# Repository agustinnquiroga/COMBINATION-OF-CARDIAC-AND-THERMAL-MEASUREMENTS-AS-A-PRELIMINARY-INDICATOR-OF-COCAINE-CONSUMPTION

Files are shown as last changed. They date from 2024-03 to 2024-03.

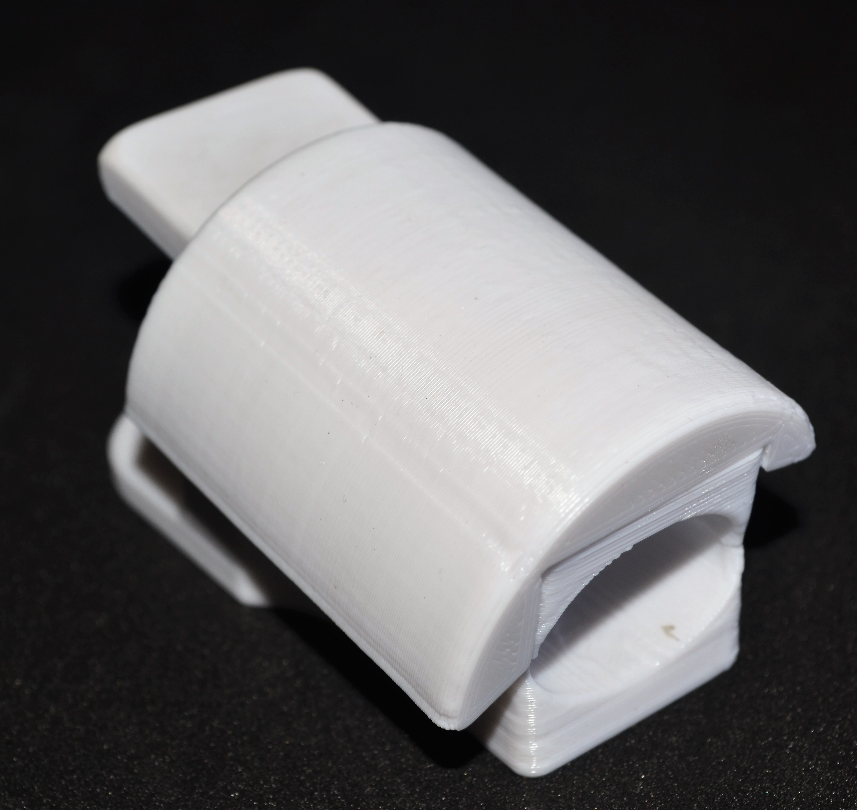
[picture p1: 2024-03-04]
DESIGN/IMAGENES/DSC_0425.JPG

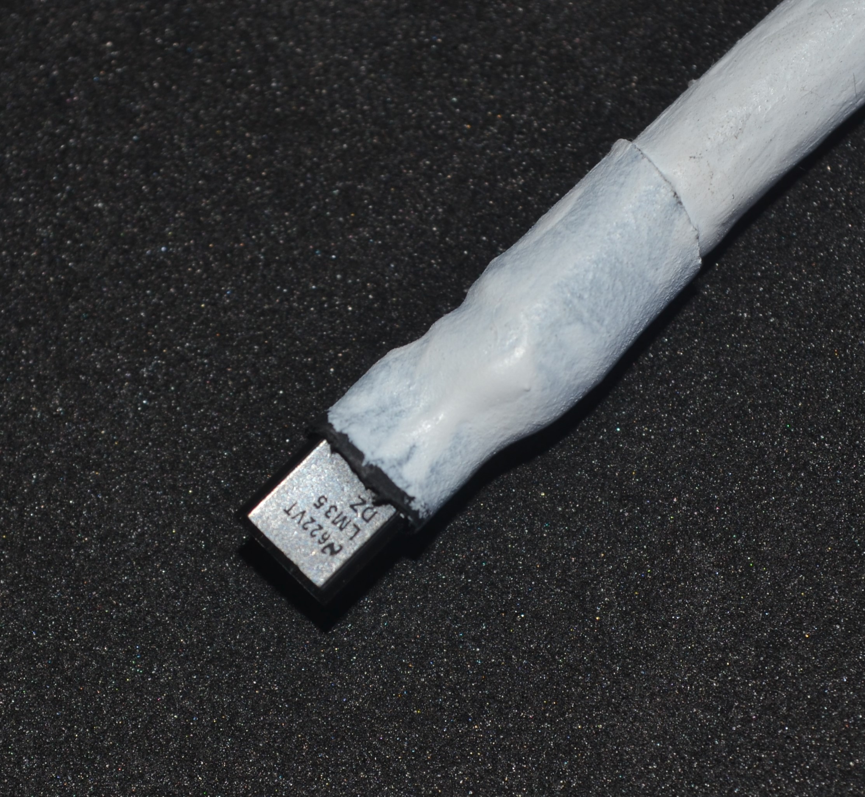
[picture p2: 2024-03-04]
DESIGN/IMAGENES/DSC_0422.JPG

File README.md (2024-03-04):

# COMBINATION-OF-CARDIAC-AND-THERMAL-MEASUREMENTS-AS-A-PRELIMINARY-INDICATOR-OF-COCAINE-CONSUMPTION

En Argentina según un estudio de la
Secretaría de Políticas Integrales sobre Drogas
de la Nación Argentina (Sedronar), el 5,3%
de la población entre 12 y 65 años consumió
cocaína alguna vez en su vida, 1,5% declaró
consumo de cocaína en el último año y 0.7% son
consumidores habituales lo que representa que
dos millones de personas admitieron consumir
alguna vez en su vida, seiscientas mil en el
último año y trescientas mil son consumidoras
recurrentes. Ya que la misma produce una
estimulación del sistema nervioso simpático
es de suma importancia detectar cuando una
persona se encuentra bajos los efectos de la
droga con el fin de que no realice actividades
que demanden el funcionamiento óptimo de
todos sus sistemas.
Entre los parámetros que altera el consumo de
cocaína se encuentran la temperatura corporal
y la frecuencia cardíaca, aumentando los valores
normales registrados para una persona que se
halla en reposo y saludable. Basándonos en los
parámetros mencionados, el presente trabajo
busca diseñar un dispositivo capaz de medir
el pulso y temperatura corporal del sujeto de
estudio, con el fin de constatar si el individuo
posee signos vitales con características similares
a los de una persona que se encuentra bajo los
efectos de la droga.
La frecuencia cardíaca se registrará a través
de un sensor infrarrojo, compuesto por un diodo
emisor de luz infrarroja y un fototransistor
receptor de estas ondas electromagnéticas. El
sensor de coloca en el dedo pulgar y es capaz de
medir los cambios de volumen de sangre en las
arterias debido a la mayor reflexión de luz. La
temperatura corporal se evaluará mediante un
sensor de temperatura analógico, colocado en la
axila del sujeto. A partir de la comparación de
los valores obtenidos se entregará un resultado.

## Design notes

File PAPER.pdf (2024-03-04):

# Test de cocaína a partir de ritmo cardíaco y temperatura corporal

### A. N. Quiroga Baigorri,∗ M. S. Moyano, G. Quintero, and P. Y. Teruya

Instituto de Bioingeniería, Facultad de Ingeniería, Universidad de Mendoza, Boulogne Sur Mer 683, Mendoza

E-mail: a.quiroga@um.edu.ar

## Resumen

En Argentina según un estudio de la Secretaría de Políticas Integrales sobre Drogas de la Nación Argentina (Sedronar), el 5,3% de la población entre 12 y 65 años consumió cocaína alguna vez en su vida, 1,5% declaró consumo de cocaína en el último año y 0.7% son consumidores habituales lo que representa que dos millones de personas admitieron consumir alguna vez en su vida, seiscientas mil en el último año y trescientas mil son consumidoras recurrentes. Ya que la misma produce una estimulación del sistema nervioso simpático es de suma importancia detectar cuando una persona se encuentra bajos los efectos de la droga con el fin de que no realice actividades que demanden el funcionamiento óptimo de todos sus sistemas.
Entre los parámetros que altera el consumo de cocaína se encuentran la temperatura corporal y la frecuencia cardíaca, aumentando los valores normales registrados para una persona que se halla en reposo y saludable. Basándonos en los parámetros mencionados, el presente trabajo busca diseñar un dispositivo capaz de medir el pulso y temperatura corporal del sujeto de estudio, con el fin de constatar si el individuo posee signos vitales con características similares a los de una persona que se encuentra bajo los efectos de la droga.
La frecuencia cardíaca se registrará a través de un sensor infrarrojo, compuesto por un diodo emisor de luz infrarroja y un fototransistor receptor de estas ondas electromagnéticas. El sensor de coloca en el dedo pulgar y es capaz de medir los cambios de volumen de sangre en las arterias debido a la mayor reflexión de luz. La temperatura corporal se evaluará mediante un sensor de temperatura analógico, colocado en la axila del sujeto. A partir de la comparación de los valores obtenidos se entregará un resultado.

## Introducción

La cocaína copia los efectos del sistema nervioso simpático, se inician todas las respuestas orgánicas asociadas a la reacción de lucha o huida: aumentan la tensión arterial y el ritmo cardíaco, contraen los vasos sanguíneos, dilatan los bronquíolos de los pulmones, aumentan el azúcar en la sangre, aumenta la temperatura corporal y, en general, preparan al cuerpo para una emergencia. ¹
En este trabajo solo se hará enfoque a las modificaciones neurológicas que tienen relación con la frecuencia cardíaca y la temperatura corporal.
La frecuencia cardíaca se registrará a través de un sensor infrarrojo, compuesto por un diodo emisor de luz infrarroja y un fototransistor receptor de estas ondas electromagnéticas. El sensor de coloca en el dedo pulgar y es capaz de medir los cambios de volumen de sangre en las arterias debido a la mayor reflexión de luz. La temperatura corporal se evaluará mediante un sensor de temperatura analógico, colocado en la axila del sujeto. A partir de la comparación de los valores obtenidos se entregará un resultado.

## Herramientas y Métodos

### Hardware

La metodología para la adquisición tanto de la señal de temperatura proveniente del sensor LM35 y de la señal de pulso procedente de el sensor de pulso consiste de las etapas detalladas en la Figura 1.

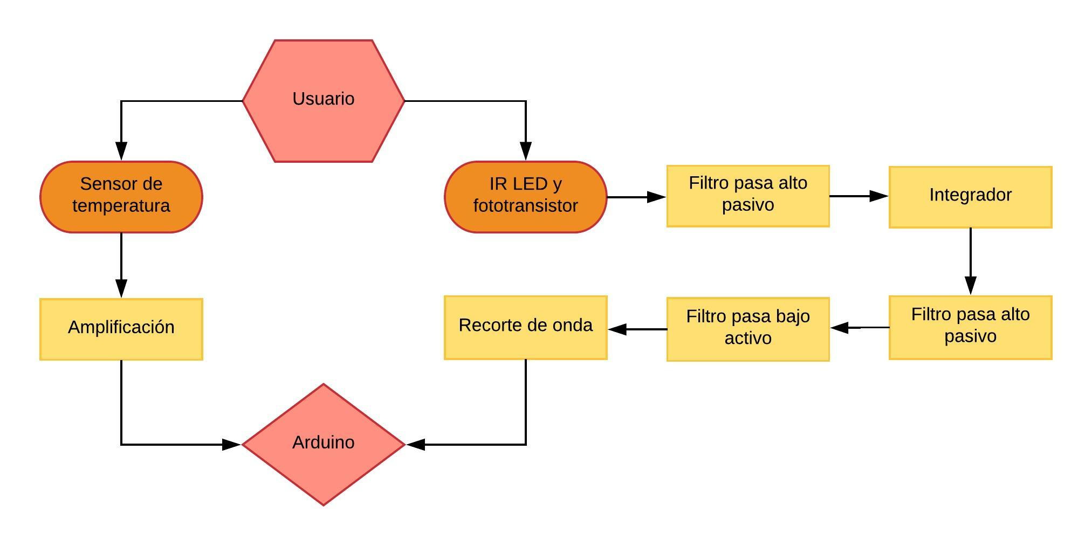
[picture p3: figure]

Figura 1: Diagrama de bloques que especifica las etapas necesarias para la obtención de las señales.

Sensor de temperatura

Se utilizó un circuito integrado LM35 con una tensión de salida lineal proporcional a la temperatura centígrada. El sensor entrega en la salida un voltaje equivalente de:

V out = 0mV + 10.0mV/◦C | (1)

Amplificación

Se acopló a la salida del integrado un amplificador de señal con ganancia de 8 para aprovechar la resolución del convertidor analógico/digital de Arduino. ²,3
En la Tabla 1 se denota el rango de temperatura que logra sensar el dispositivo, junto con las tensiones que se obtendrán a la salida del sensor y luego de que la señal sea amplificada.

Tabla 1: Voltajes

Temperatura Vout LM35 Vout Amp. 4

◦C | 40mV | 0.32V
35◦C | 350mV | 2.8V
40◦C | 400mV | 3.2V
62.5◦C | 625mV | 5V

Sensor de pulso

El pulsómetro se basa en un sensor infrarrojo, compuesto por un diodo emisor de luz infrarroja (IR LED) y un fototransistor receptor de estas ondas electromagnéticas. Las etapas de acondicionamiento de la señal son:

IR LED y fototransistor

Se utilizó un IR LED L53 el cual tiene una corriente máxima de alimentación de 50mA. En tanto el fototransistor se colocó en una configuración emisor común con una corriente mínima de alimentación de 0.1mA.

Filtro pasa alto pasivo

Se acopló un filtro pasa alto pasivo con la finalidad de amortiguar el ruido que posee frecuencias hasta 2.34Hz. Esta etapa tiene también la función de desacoplar la componente continua de la corriente gracias a la utilización de un capacitor en serie con la salida del fototransistor.
Un filtro con las mismas características se adjunta a la salida del amplificador operacional integrador no inversor.

Amplificador operacional integrador no inversor

Se acopla a la salida del filtro pasa alto pasivo un amplificador operacional integrador no inversor, debido a este tratamiento se consigue una señal más nítida y estable. Teniendo en cuenta la señal de entrada se decidió colocar una resistencia de 8.2KΩ y un capacitor de 0.1µF en la disposición característica de este operacional.

Filtro pasa bajo activo

Luego se acopló un filtro pasa bajo activo con la finalidad de amortiguar las frecuencias mayores a 3.39Hz. La ganancia de este filtro es de 471.

Recorte de onda

La señal a la salida del filtro pasa bajo activo posee picos que superan el rango de voltajes de la entrada analógica de Arduino, debido a esto se realiza un recorte de onda mediante un transistor NPN 2N3904 dispuesto en una configuración colector común.
Esta configuración proporciona una función de adaptador de impedancia debido a la alta impedancia de entrada y su baja impedancia de salida.

### Software

El paso siguiente consiste en la programación del microcontrolador de la placa Arduino usando Arduino Programming Language y el Arduino Development Environment, basados en Wiring y Processing respectivamente. Esta programación se realiza con el fin de llevar a cabo una correcta conversión analógico/digital de ambas señales. Cabe destacar que debido a la incapacidad de Arduino de realizar varios procesos simultáneamente y la practicidad de realizar la interfaz gráfica se utilizó Python 3.7. El diagrama de flujo de la etapa digital se muestra en la Figura 2.

Arduino

Temperatura corporal

La señal luego de ser procesada analógicamente llega a la entrada A5 de Arduino. El sensor LM35 entrega un voltaje de 10mV por grado centígrado y luego de una amplificación con ganancia 8 el circuito entregara 80mV por grado centígrado. Teniendo en cuenta esto la ecuación para la conversión es la siguiente:

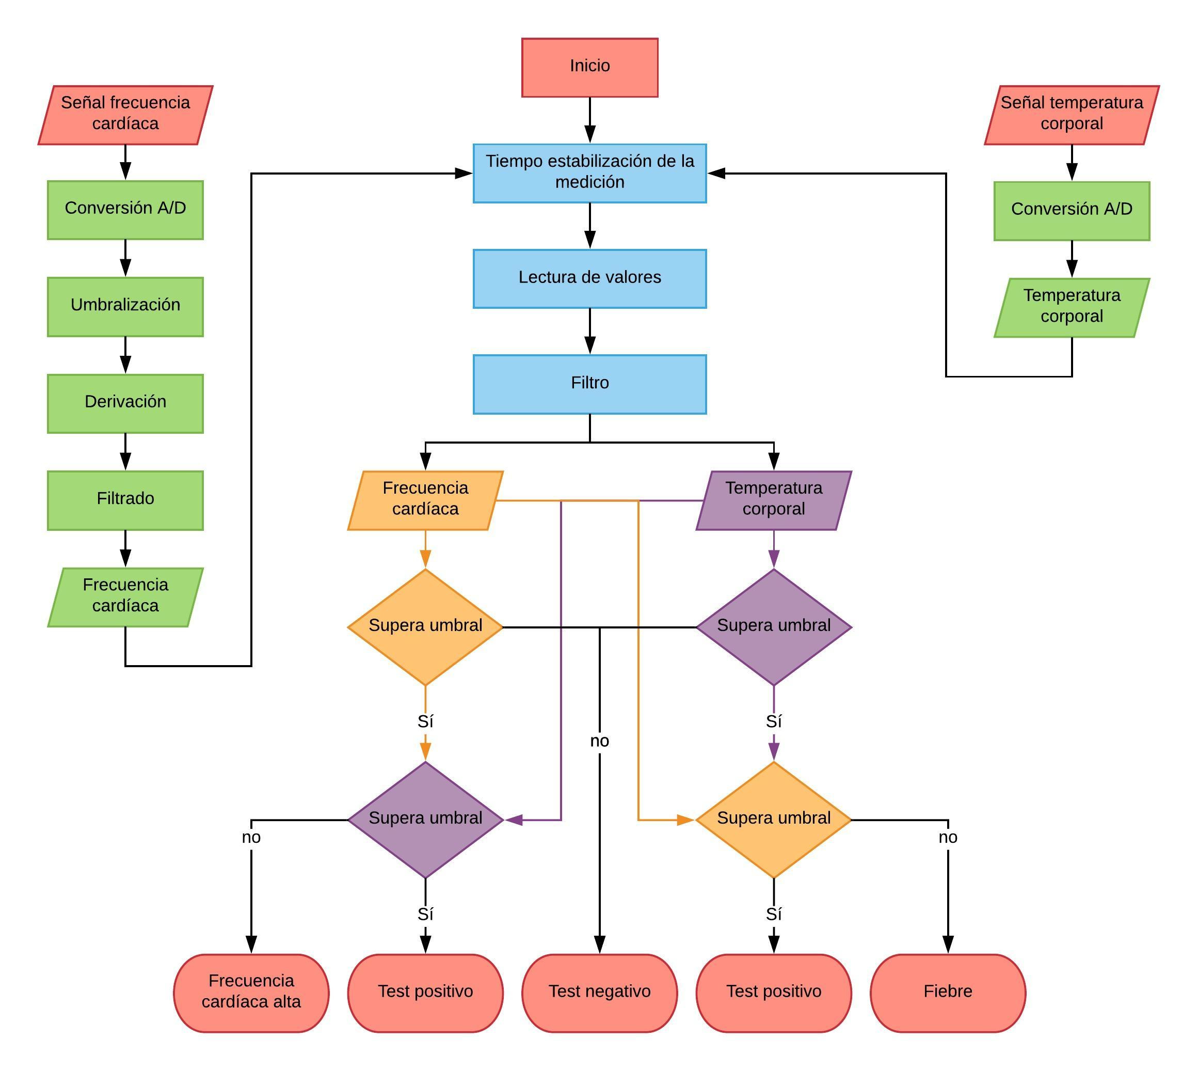
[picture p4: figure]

Figura 2: | Diagrama de flujo. | Las figuras en
color verde corresponden etapas realizadas en Arduino mientras que las celestes en adelante corresponden a etapas en Python 3.7

temperatura = ((V in × 5 ÷ 1024) ÷ 0.08 (2)

Frecuencia cardíaca

La señal luego de ser procesada analógicamente y que llega a la entrada A0 de Arduino es la siguiente:

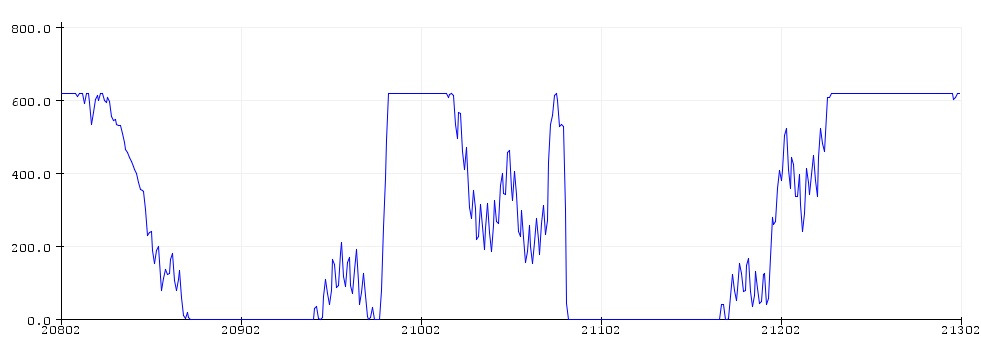
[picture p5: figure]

Figura 3: Señal luego del procesamiento analógico.

Si bien es bastante definida se debe realizar una umbralización para que sea completamente cuadrada. Para realizar esta tarea se utilizó la librería Threshold.
Luego de este tratamiento se prosiguió a la derivación de la señal para poder detectar el flanco ascendente de la señal. Para esto se realizó el límite del cociente incremental. Después se calculó el tiempo entre impulso e impulso de la señal derivada y este es el valor de la frecuencia cardíaca instantánea. En este punto se realizó un filtro para eliminar valores de frecuencia cardíaca que estén por debajo de 50 y por encima de 200 debido a que son mediciones erróneas.
Para finalizar se le realizó otro filtro con el fin de eliminar valores erróneos que no eliminara el filtro anterior. El filtro se logró mediante la determinación de una mediana móvil de la frecuencia con una “ventana” de 5 valores. Para ello se utilizó la librería MedianFilter.

Python 3.7

Los | valores | de | frecuencia | cardíaca | y
temperatura corporal se “levantan” en Python 3.7 a través del puerto serie COM3 mediante el módulo serial.
El primer proceso que se realiza es el de esperar 4 minutos para empezar a almacenar los valores procedentes de Arduino. Esta espera se realiza debido a que, el sensor de temperatura tarda como mínimo 4 minutos para estabilizar su medición. A partir de transcurrido este lapso el programa empieza a “levantar ” tanto valores de frecuencia cardíaca como de temperatura corporal.
Luego de obtener 11 valores el programa los almacena en variables separadas con atributos de lista y calcula la mediana de estos por medio del módulo numpy y su función median. Esto actúa como un filtro con la finalidad de evitar guardar valores erróneos.
Una vez que se tienen las magnitudes de frecuencia cardíaca y temperatura corporal del sujeto se prosigue, mediante estructuras condicionantes if, elif y else, a evaluar si los valores de los parámetros corresponden a una persona que se encuentra bajos los efectos de la cocaína. Los valores umbrales utilizados son para la frecuencia cardíaca: 110 pulsaciones por minuto y la temperatura corporal: 38◦C. Basándose en esto el test devuelve resultados como los que se aprecian en la Figura 2 en recuadros rojos.
Para realizar el proceso de exhibición de resultados, mediante interfaz gráfica, como el de almacenamiento de las variables y su respectivo tratamiento se utilizó el módulo threading.

Interfaz gráfica

La interfaz gráfica se produjo por medio del módulo wx y consta de una ventana con los siguientes mensajes:

- Como se observa en la Figura 4, la ventana inicial posee el mensaje “Coloque el termómetro y el dedo pulgar. Luego seleccione comenzar.”. Además contiene un temporizador de 5 minutos el cual se inicia al hacer clic en el botón “Comenzar ” que se encuentra en el extremo inferior derecho.

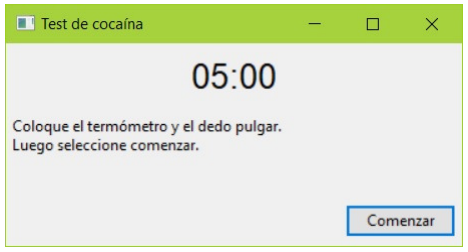
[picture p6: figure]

Figura 4: Ventana y mensaje inicial

- Luego de clicar sobre el botón el programa comienza con los procesos explicados anteriormente, el temporizador empieza a funcionar y se exhibe el aviso “Aguarde por favor...”.
- Una vez transcurrido el tiempo el programa expone los resultados del test en el siguiente formato:

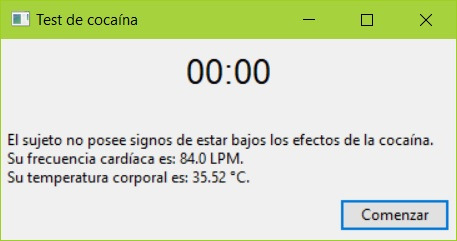
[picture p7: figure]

Figura 5: Ventana con los resultados

## Resultados

- La maqueta final del dispositivo se puede contemplar en la siguiente imagen:

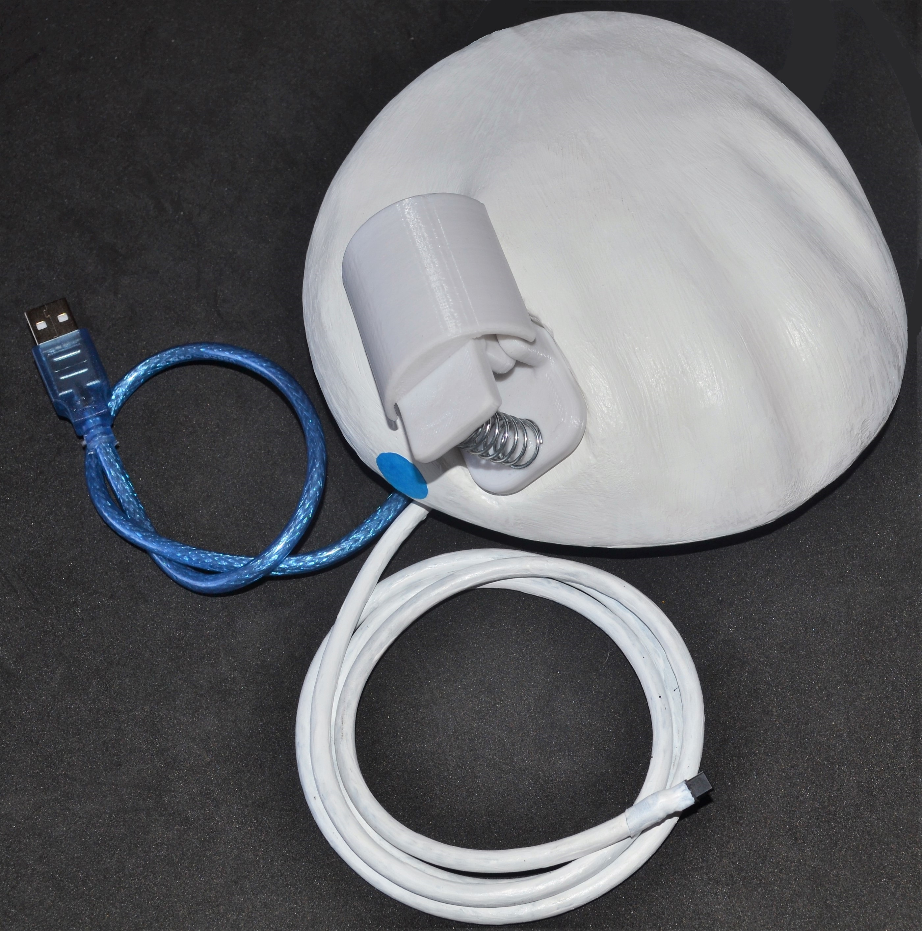
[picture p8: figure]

Figura 6: Maqueta del dispositivo

- Los valores de temperatura corporal que otorga el test se compararon con los medidos por un termómetro digital San-Up y difieren en ±10 centésimos
- Los valores de frecuencia cardíaca que otorga el test se compararon con los medidos por la aplicación Samsung Health de un Samsung S8 con sensor de pulso y difieren en ±1 pulso por minuto.

## Conclusiones

- El acondicionamiento analógico de la señal de temperatura corporal no reviste grandes complicaciones.
- Python 3.7 posee módulos muy potentes como numpy, serial, threading y wx pero se necesita de un gran conocimiento y sobre todo de mucha práctica para sacar provecho de todas las funciones que integran estos módulos.
- Se necesitaron varios filtros digitales tanto en Arduino como en Python 3.7 para lograr obtener valores correctos de frecuencia cardíaca. Siendo el filtro de mediana el más eficiente.
- El diseño es un aspecto esencial en el desarrollo de un producto. La fabricación de maquetas y prototipos en 3D a primera vista parece una tarea sencilla, pero nada más alejado de la realidad, debido que conlleva cuantioso tiempo y dedicación para lograr los resultados esperados.
- Con respecto a la adecuación de la señal de frecuencia cardíaca se puede concluir que a pesar de que con las diferentes etapas realizadas se logra una señal aceptable, con la incorporación de un número mayor de fases de filtrado se lograría una señal aún más estable.

## Trabajo futuro

- Agregar | etapas | de | filtrado | en | el
acondicionamiento analógico de la señal de frecuencia cardíaca.
- Mejorar el dedal en aspectos relacionados a presión ejercida sobre el dedo y la captación de la señal.
- Añadir al programa del test la instrucción de introducir la edad del sujeto de estudio con el fin de que el umbral de frecuencia cardíaca sea aún más específico.
- Aumentar los parámetros de análisis del test, tales como presión arterial, midriasis permanente, etc.
- Globalizar | el | test | para | cualquier
droga estimulante como anfetaminas, metanfetaminas, efedrina, metilfenidato, metcatinona y éxtasis.
- Construcción de la base del dispositivo a partir de polímeros.
- Construir un dispositivo inalámbrico mediante uso de baterías y conexión bluetooth o wifi.

- Creación | de | una | aplicación | para
smartphones donde se visualicen los resultados del test.
- Diseño de una versión transportable.

## References

(1) Kuhn, C.; Swartzwelder, S.; Wilson, W. Colocados: lo que hay que saber sobre drogas más consumidas, desde el alcohol hasta el éxtasis. Colocados: lo que hay que saber sobre drogas más consumidas, desde el alcohol hasta el éxtasis 2011,
(2) Instruments, T. LM35 Datasheet. 1999,
(3) Arduino, Arduino Uno Datasheet.

Acknowledgement El autor quiere agradecer a todas las personas que colaboraron con la realización de este proyecto.

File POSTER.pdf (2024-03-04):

# Test de cocaína a partir de ritmo card´ ıaco y temperatura corporal

## A. N. Quiroga Baigorria

∗

## , M. S. Moyanoa

## , G. Quinteroa , P. Y. Teruya

a

a

∗
Instituto de Bioingeniería, Facultad de Ingeniería, Universidad de Mendoza, Boulogne Sur Mer 683, Mendoza
∗
a.quiroga@um.edu.ar

## Introduccion

´

En Argentina segun un estudio de la Secretar ´ | ía de Políticas Integrales sobre Drogas de la Nacion Argentina (Sedronar), el 5,3% de la poblaci ´ | on entre 12 y 65 a ´ | nos consumi ˜ | o coca ´ | ína alguna vez en su vida y el 1,5% declaró
consumo de cocaína en el ultimo a ´ | no. Esta droga produce una estimulaci ˜ | on del sistema nervioso simp ´ | atico, movimiento deliberado de manos y pies, una euforia inequ ´ | ívoca y activa las respuestas organicas asociadas a la ´
reaccion de lucha o huida. Por ello, es de suma importancia detectar cuando una persona se encuentra bajos los efectos de la droga con el fin de evitar que realice actividades que puedan afectar a terceros. ´ | | | | | 1
El consumo de cocaína altera, entre otros parametros, la temperatura corporal y la frecuencia card ´ | íaca aumentando sus valores normales para una persona que se halla en reposo. A partir de lo expuesto, el presente trabajo busca
disenar un dispositivo capaz de detectar dichas variaciones. ˜ | 2

## Objetivos

Disenar un dispositivo con los fines de detectar frecuencia card ˜ | íaca y temperatura corporal de un sujeto,
para inferir si este posee signos vitales con caracter ´ | ísticas similares a los de una persona que se encuentra
bajo los efectos de la cocaína.

## Herramientas y Metodos ´

### Etapa analogica ´

La frecuencia cardíaca se registra a traves de un sensor infrarrojo, compuesto por un diodo emisor de ´ luz infrarroja y un fototransistor receptor de estas ondas electromagneticas. El sensor de coloca en el dedo ´ pulgar y es capaz de medir los cambios de volumen de sangre en las arterias debido a la mayor reflexion de ´
luz. La temperatura corporal se evalua mediante un sensor de temperatura anal ´ | ogico, colocado en la axila ´
del sujeto.
Con el fin de acondicionar las senales para su futuro procesamiento digital, se aplican una serie de etapas ˜ las cuales se pueden observar en la siguiente imagen:


Figura 1: Diagrama de bloques.

La ganancia del amplificador de la senal de temperatura es de 8. En las etapas de filtrado de frecuencias ˜
bajas, de la senal proveniente del sensor infrarrojo, se utiliz ˜ | o una frecuencia de corte de 2.34Hz. La fase ´
de integracion se realiz ´ | o por medio de un amplificador operacional en configuraci ´ | on integrador con una ´
resistencia de 8.2KΩ y un capacitor de 0.1µF. El filtro pasa bajo activo posee una frecuencia de corte de
3.39Hz y una ganancia de 471. El recorte de onda se logro gracias a la utilizaci ´ | on de un transistor NPN en ´
configuracion colector com ´ | un. ´

### Etapa digital

Utilizando un circuito embebido, en este caso Arduino, se realiza la conversion anal ´ ogica/digital de las ´ senales y se llevan a cabo las etapas de procesamiento que se observan en la figura 2 en recuadros de color ˜ verde.

Luego del procesamiento en el entorno Arduino se obtienen valores de frecuencia cardíaca y temperatura
corporal que son “levantados” en el lenguaje de programacion interpretado ´ | Python 3.7 a traves del puerto ´
serie COM3 y se les realiza el procesamiento que se aprecia en el diagrama de flujo en los recuadros azules en adelante.
Por ultimo, se eval ´ | ua si los valores de los par ´ | ametros corresponden a una persona que se encuentra bajos ´
los efectos de la cocaína y segun esta comparaci ´ | on el test devuelve los resultados que se aprecian en el final ´
del diagrama.


Figura 2: Diagrama de flujo.

## Resultados

- La maqueta final del dispositivo se puede apreciar en la siguiente imagen:

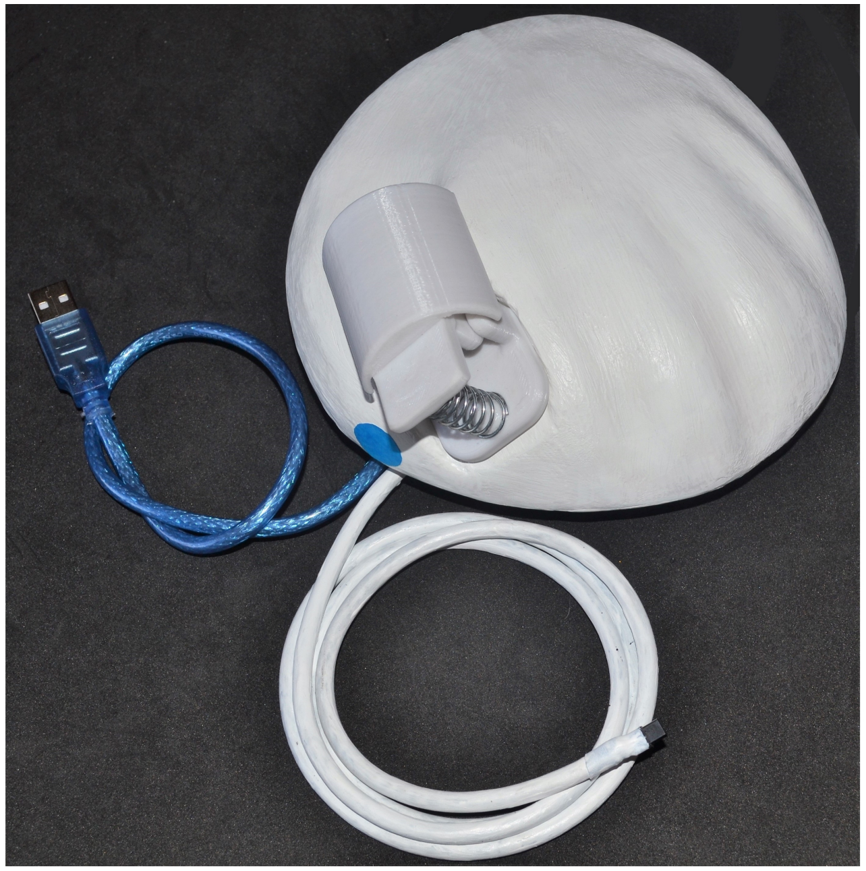
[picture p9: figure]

Figura 3: Maqueta del dispositivo.

- Los valores de temperatura corporal que otorga el test se compararon con los medidos por un termometro ´ digital San-Up y difieren en ±10 centesimos ´
- Los valores de frecuencia cardíaca que otorga el test se compararon con los medidos por la aplicacion´ Samsung Health de un Samsung S8 con sensor de pulso y difieren en ±1 pulso por minuto.

## Conclusiones

- El acondicionamiento analogico de la se ´ | nal de temperatura corporal no reviste grandes complicaciones. ˜
- La adecuacion de la se ´ | nal de frecuencia card ˜ | íaca lograda es aceptable, pero con la incorporacion de ´
mayor numero de fases de filtrado anal ´ | ogico se obtendr ´ | ía una senal m ˜ | as estable. ´
- Se necesitaron varios filtros digitales tanto en Arduino como en Python 3.7 para lograr obtener valores correctos de frecuencia cardíaca. Siendo el filtro de mediana el mas eficiente. ´
- El diseno es un aspecto esencial en el desarrollo de un producto. La fabricaci ˜ | on de maquetas y prototi- ´
pos 3D conlleva cuantioso tiempo y dedicacion para lograr los resultados esperados. ´

## Trabajo Futuro

- Agregar etapas de filtrado en el acondicionamiento analogico de la se ´ | nal de frecuencia card ˜ | íaca.
- Mejorar el dedal en aspectos relacionados a presion ejercida sobre el dedo y la captaci ´ | on de la se ´ | nal. ˜
- Anadir el requerimiento de introducir la edad del sujeto de estudio con el fin de especificar el umbral ˜ de frecuencia cardíaca.
- Aumentar los parametros de an ´ | alisis del test, tales como presi ´ | on arterial, midriasis permanente, etc. ´
- Globalizar el test para que se detecte el consumo de cualquier droga estimulante.
- Construir version inal ´ | ambrica del dispositivo mediante uso de bater ´ | ías y conexion bluetooth o wifi. ´

Referencias

[1]: M. Somoza, Consumo de cocaína. Estudio nacional en poblacion de 12 a 65 a ´ | nos sobre consumo de sustancias psicoactivas. Argentina, 2017 ˜ | .
[2]: C. Kuhn, S. Swartzwelder and W. Wilson, Colocados: lo que hay que saber sobre drogas mas consumidas, desde el alcohol hasta el ´ | extasis, 2011 ´

Agradecimientos

El autor quiere agradecer a todas las personas que colaboraron con la realizacion de este proyecto. ´

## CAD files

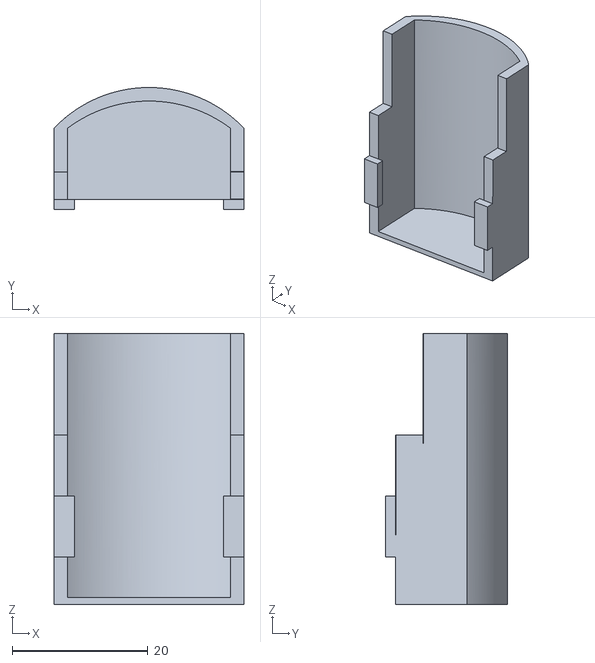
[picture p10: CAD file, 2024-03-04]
DESIGN/Dedal/1.0/tapa.stl
28.0 x 18.0 x 40.0

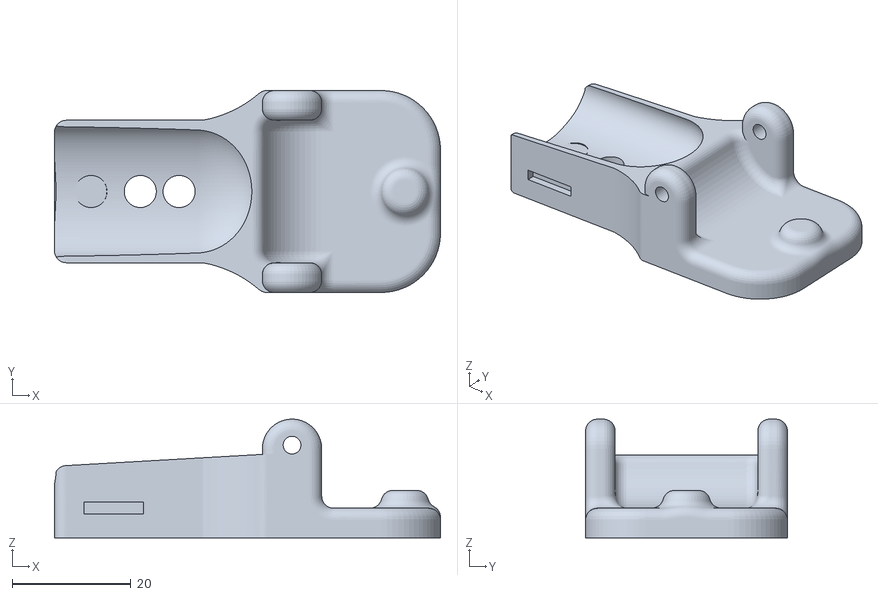
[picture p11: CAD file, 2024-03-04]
DESIGN/Dedal/2.0/base.stl
65.0 x 34.0 x 20.0

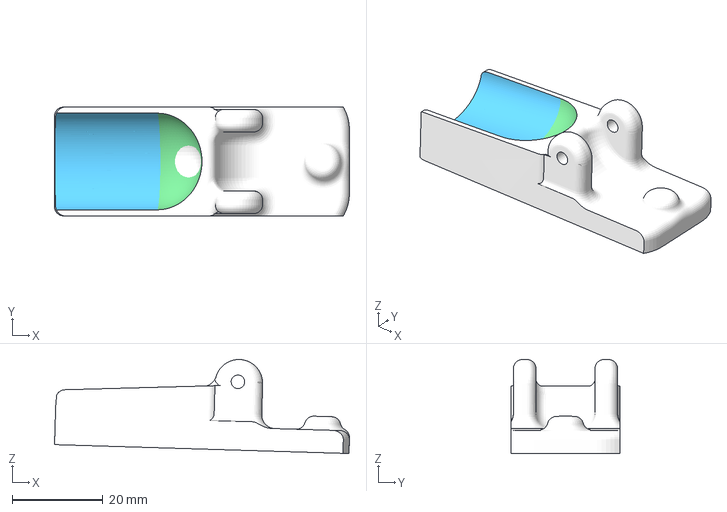
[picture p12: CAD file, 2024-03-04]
DESIGN/Dedal/parte de arriba sin redondear.3mf
65.1 x 24.0 x 20.7 mm

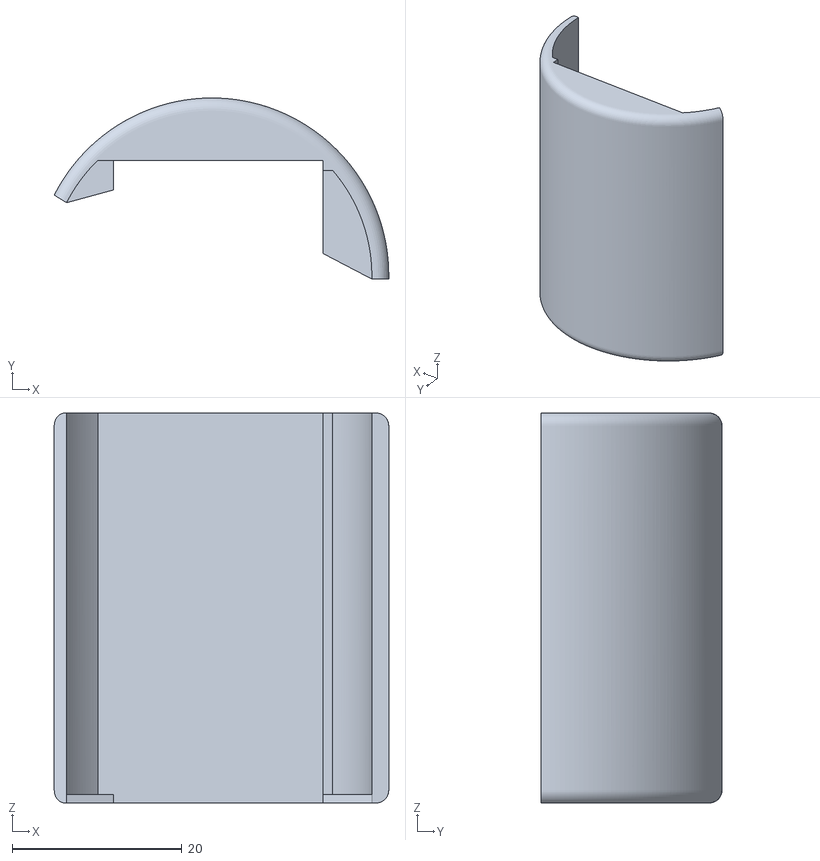
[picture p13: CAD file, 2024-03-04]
DESIGN/Dedal/2.0/curvas.stl
39.5 x 21.4 x 46.0

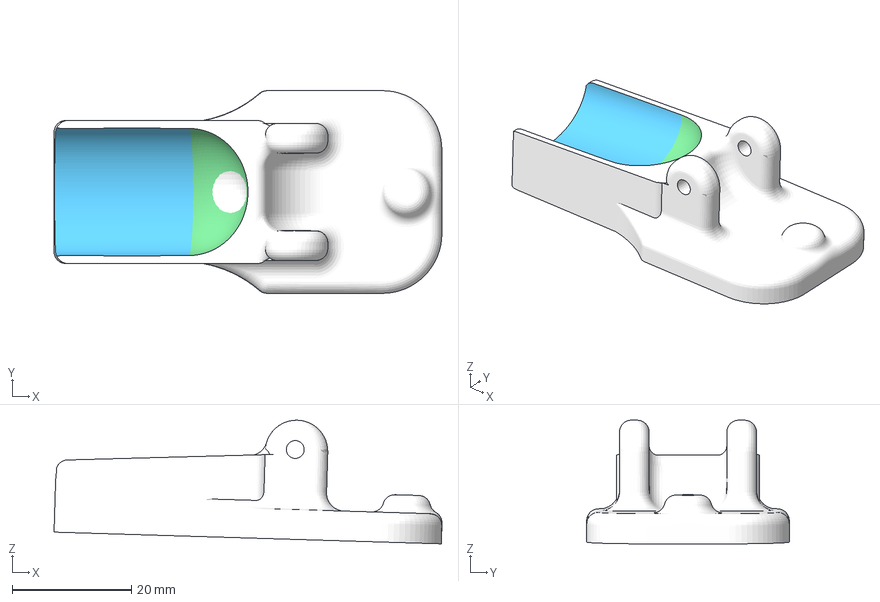
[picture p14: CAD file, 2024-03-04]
DESIGN/Dedal/1.0/nahu1.3mf
65.1 x 34.0 x 20.7 mm

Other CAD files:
DESIGN/Dedal/1.0/nahu2.3mf
DESIGN/Dedal/2.0/parte de arriba sin redondear.stl

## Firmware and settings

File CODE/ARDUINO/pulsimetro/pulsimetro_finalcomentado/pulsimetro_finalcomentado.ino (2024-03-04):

#include "ThresholdLib.h"
#include "MedianFilterLib.h"

Threshold<int> threshold(500, 100); // Valores umbralizadores, (1,0)
MedianFilter<int> medianFilter(5); // Único parametro de la función que calcula la mediana, toma (x) valores

//Variables para medir el tiempo entre muestra y muestra
 unsigned long pasado = 0; 
 unsigned long ahora ;
 unsigned long tiempo;
 unsigned long diferencialtiempo;
 unsigned long diferencialpulso;
 
 unsigned long pulso; //variable donde se almacena el valor leído de el pin A0
 int derivada; // Variable donde se guarda la señal derivada
 unsigned long umbralizadapasada = 0; // Variable donde se guarda la señal umbralizada

 // Variables utilizadas para medir el tiempo entre pulso y pulso
 unsigned long fc; // Variable donde se guarda el valor de frecuencia cardíaca
 unsigned long tiemposegundo;
 unsigned long tiempoprimero = 0;
 unsigned long tiempopulso;

// Configuración funciones que corren solo una vez
void setup() 
{
  Serial.begin(9600);// Configuracion del puerto serial a 9600 bps 
}
// Funciones en loop
void loop() 
{
   unsigned long tiempo=micros(); //variables para medir el tiempo entre muestra y muestra, micros() cuenta en microsegundos;
 
 
    pulso = analogRead(0); // lectura analógica del pin A0
    Serial.println(pulso);

 // Calcular filtro
    bool umbralizada = threshold.AddValue(pulso); //Función de la librería para umbralizar 
    
 // Mostrar resultados   
    // Serial.println(pulso); //Grafica el pulso como llega a arduino
    // Serial.println(umbralizada * 500);  //Grafica la señal umbralizada

 // Derivación

    ahora= tiempo;
    diferencialtiempo = ahora - pasado ;
    diferencialpulso= umbralizada - umbralizadapasada ;
    derivada = (diferencialpulso/diferencialtiempo) ;
    umbralizadapasada=umbralizada;
    pasado = ahora;
    
 // Mostrar derivada    
    //Serial.println(derivada);

 // Calculo de FC
 
    if (derivada > 0){ 
      tiemposegundo = ahora;
      tiempopulso = tiemposegundo - tiempoprimero;
      
      if ((tiempopulso < 1200000) && (tiempopulso > 300000)){
        //if (tiempopulso > 272727){
          
          fc= 60000000/tiempopulso;
 
          // Calcular mediana movil
          
            int mean = medianFilter.AddValue(fc);; //calcula mediana

          // Mostrar resultados
            //Serial.print(fc);
            //Serial.print("\t");
            //Serial.println(mean);

             //}    
      }
      tiempoprimero = tiemposegundo; 
    }      
}

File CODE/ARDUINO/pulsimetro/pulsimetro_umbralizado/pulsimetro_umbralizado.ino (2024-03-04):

#include "ThresholdLib.h"

Threshold<int> threshold(599, 200); // Valores umbralizadores, (1,0)

void setup() 
{
  Serial.begin(9600);
 
}

void loop() 
{
 int pulso; //variable donde se almacena el valor leído de el pin A0
 pulso = analogRead(0); // lectura analógica del pin A0

    // Calcular filtro
    bool state = threshold.AddValue(pulso); //Función de la librería para umbralizar 

////////// Mostrar resultados
    
    //Serial.println(pulso); //Grafica el pulso como llega a arduino
    Serial.println(state * 500);  //Grafica la señal umbralizada
  
}
